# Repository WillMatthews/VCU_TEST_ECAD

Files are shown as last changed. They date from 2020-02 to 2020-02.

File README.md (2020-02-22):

# VCU TEST ECAD
VCU to Beaglebone breakout hardware for testing the VCU, and future continuous integration work.

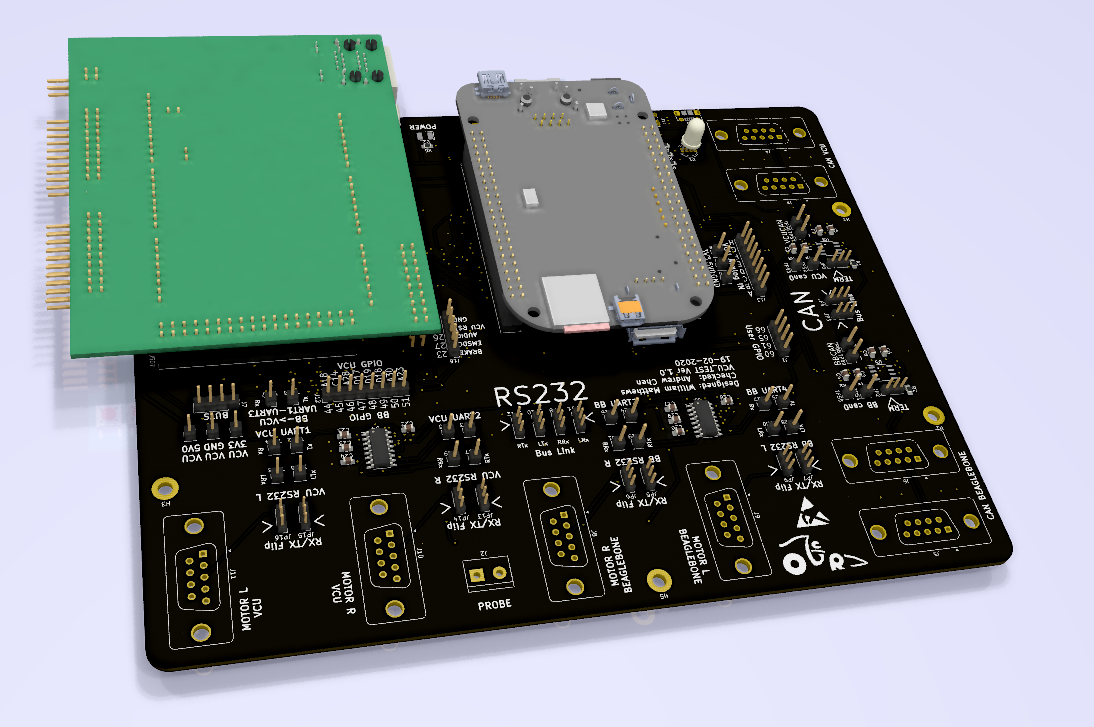
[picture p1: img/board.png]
Board Image


## Schematic and PCB

The project is made in KiCad. Which can be obtained for free! [KiCad 5.0](http://kicad-pcb.org/download/)
All project files are in the `Kicad/` subdirectory.

## Components

The design is made for power supply of 5V from either a MicroUSB or USBC power supply.
The target current consumption by this device is 1A under load, but may be higher.

We use a SAM e70 Xplained evaluation kit as the VCU.

A Beaglebone black as the test host.

### CAN
We use TCAN1042 CAN transcievers.

Both on can0 of VCU and Beaglebone.

### RS232 (Motor Emulation)
We use MAX 3232 chips for:

LEFT: Beaglebone UART2, VCU UART 1

RIGHT: Beaglebone UART4, VCU UART 2

## Signals
See pinreference_bb_vcu.ods for which beaglebone GPIOs go where (needs updating)!

## Continuous Integration
We plan to use Jenkins CI, but this is yet to be figured out and made a reality.

## Future Work

We also have plans for a DAC daughterboard to supply analogue signals to the sensors on VCU, reference also on above document.

THINGS TO DO:
- [ ] Does TLV5631 actually have SPI or is the datasheet blatantly lying to my face?
  - Now made a "daugherboard" project if required.
- [x] Put correct CAN chips
- [ ] Confirm design with team
- [x] Layout
- [x] GET LAYOUT FOR THE VCU PINS !!! Cannot find anywhere !!!
- [ ] Start test software repo
- [ ] Better documentation for pins

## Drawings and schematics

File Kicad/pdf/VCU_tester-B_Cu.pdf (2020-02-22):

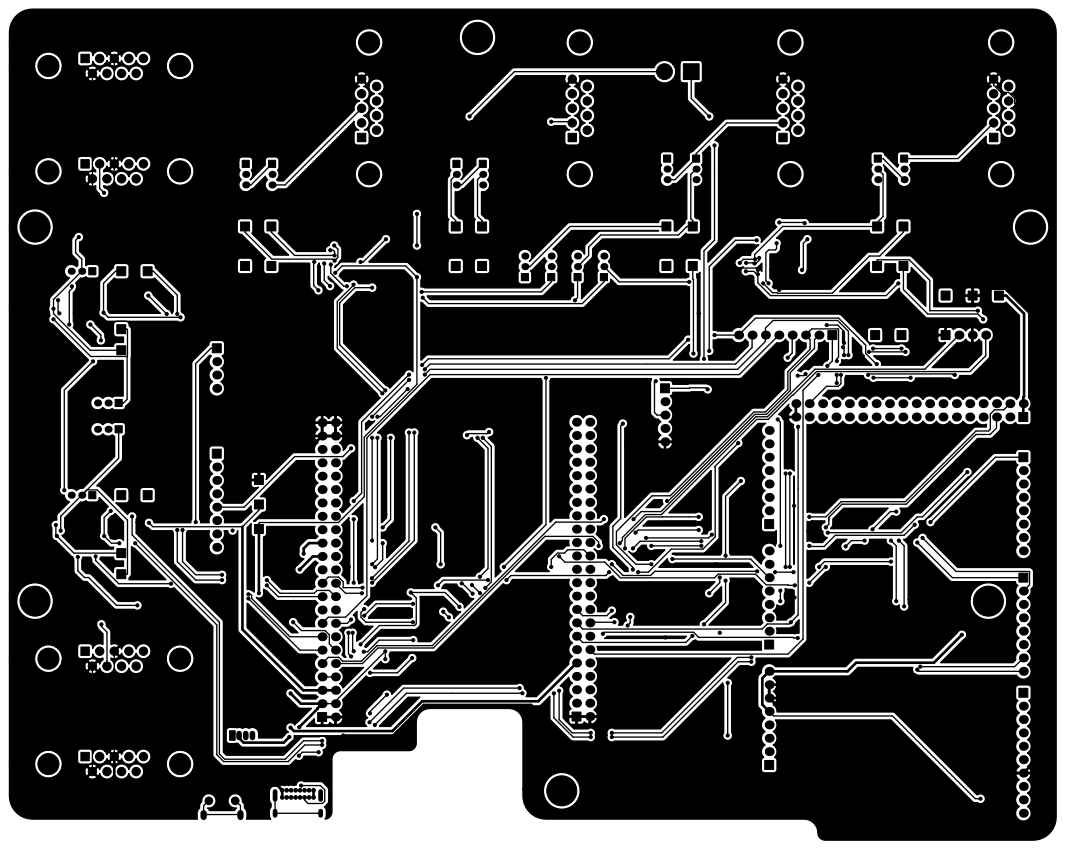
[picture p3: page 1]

File: VCU_tester.kicad_pcb Sheet:
Id: 1/1 Title: VCU Test Board

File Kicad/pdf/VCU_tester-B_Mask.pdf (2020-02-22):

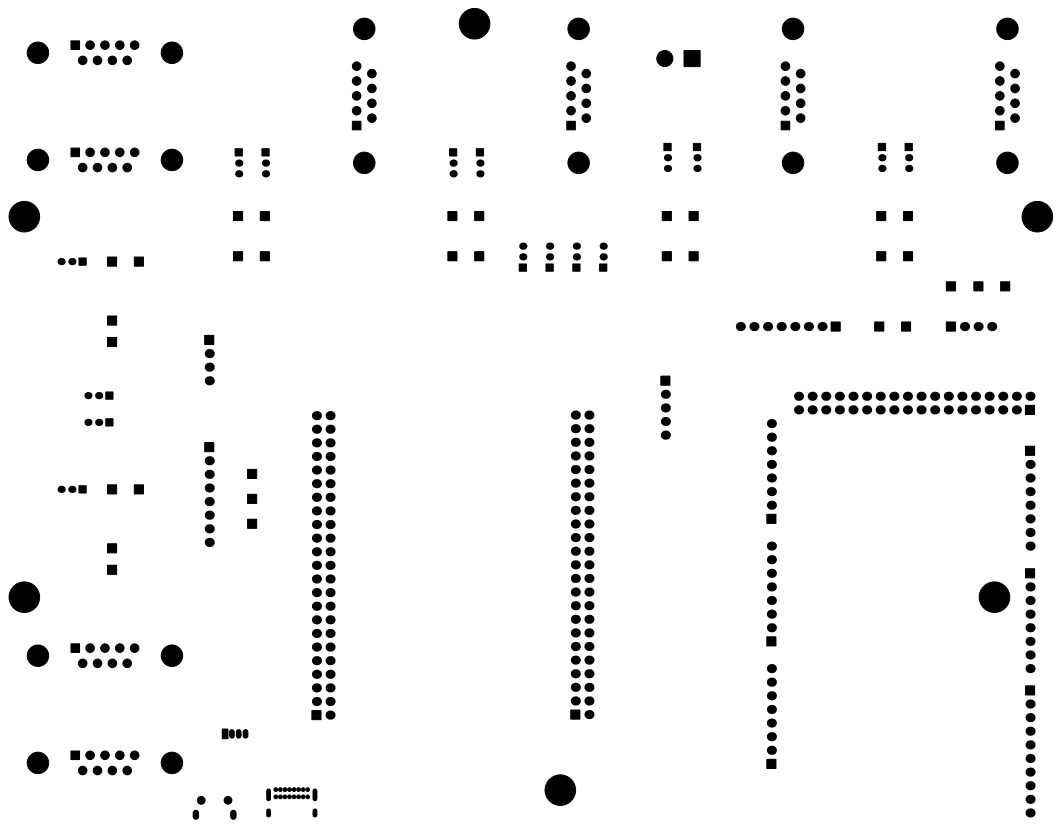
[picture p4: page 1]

File: VCU_tester.kicad_pcb Sheet:
Id: 1/1 Title: VCU Test Board

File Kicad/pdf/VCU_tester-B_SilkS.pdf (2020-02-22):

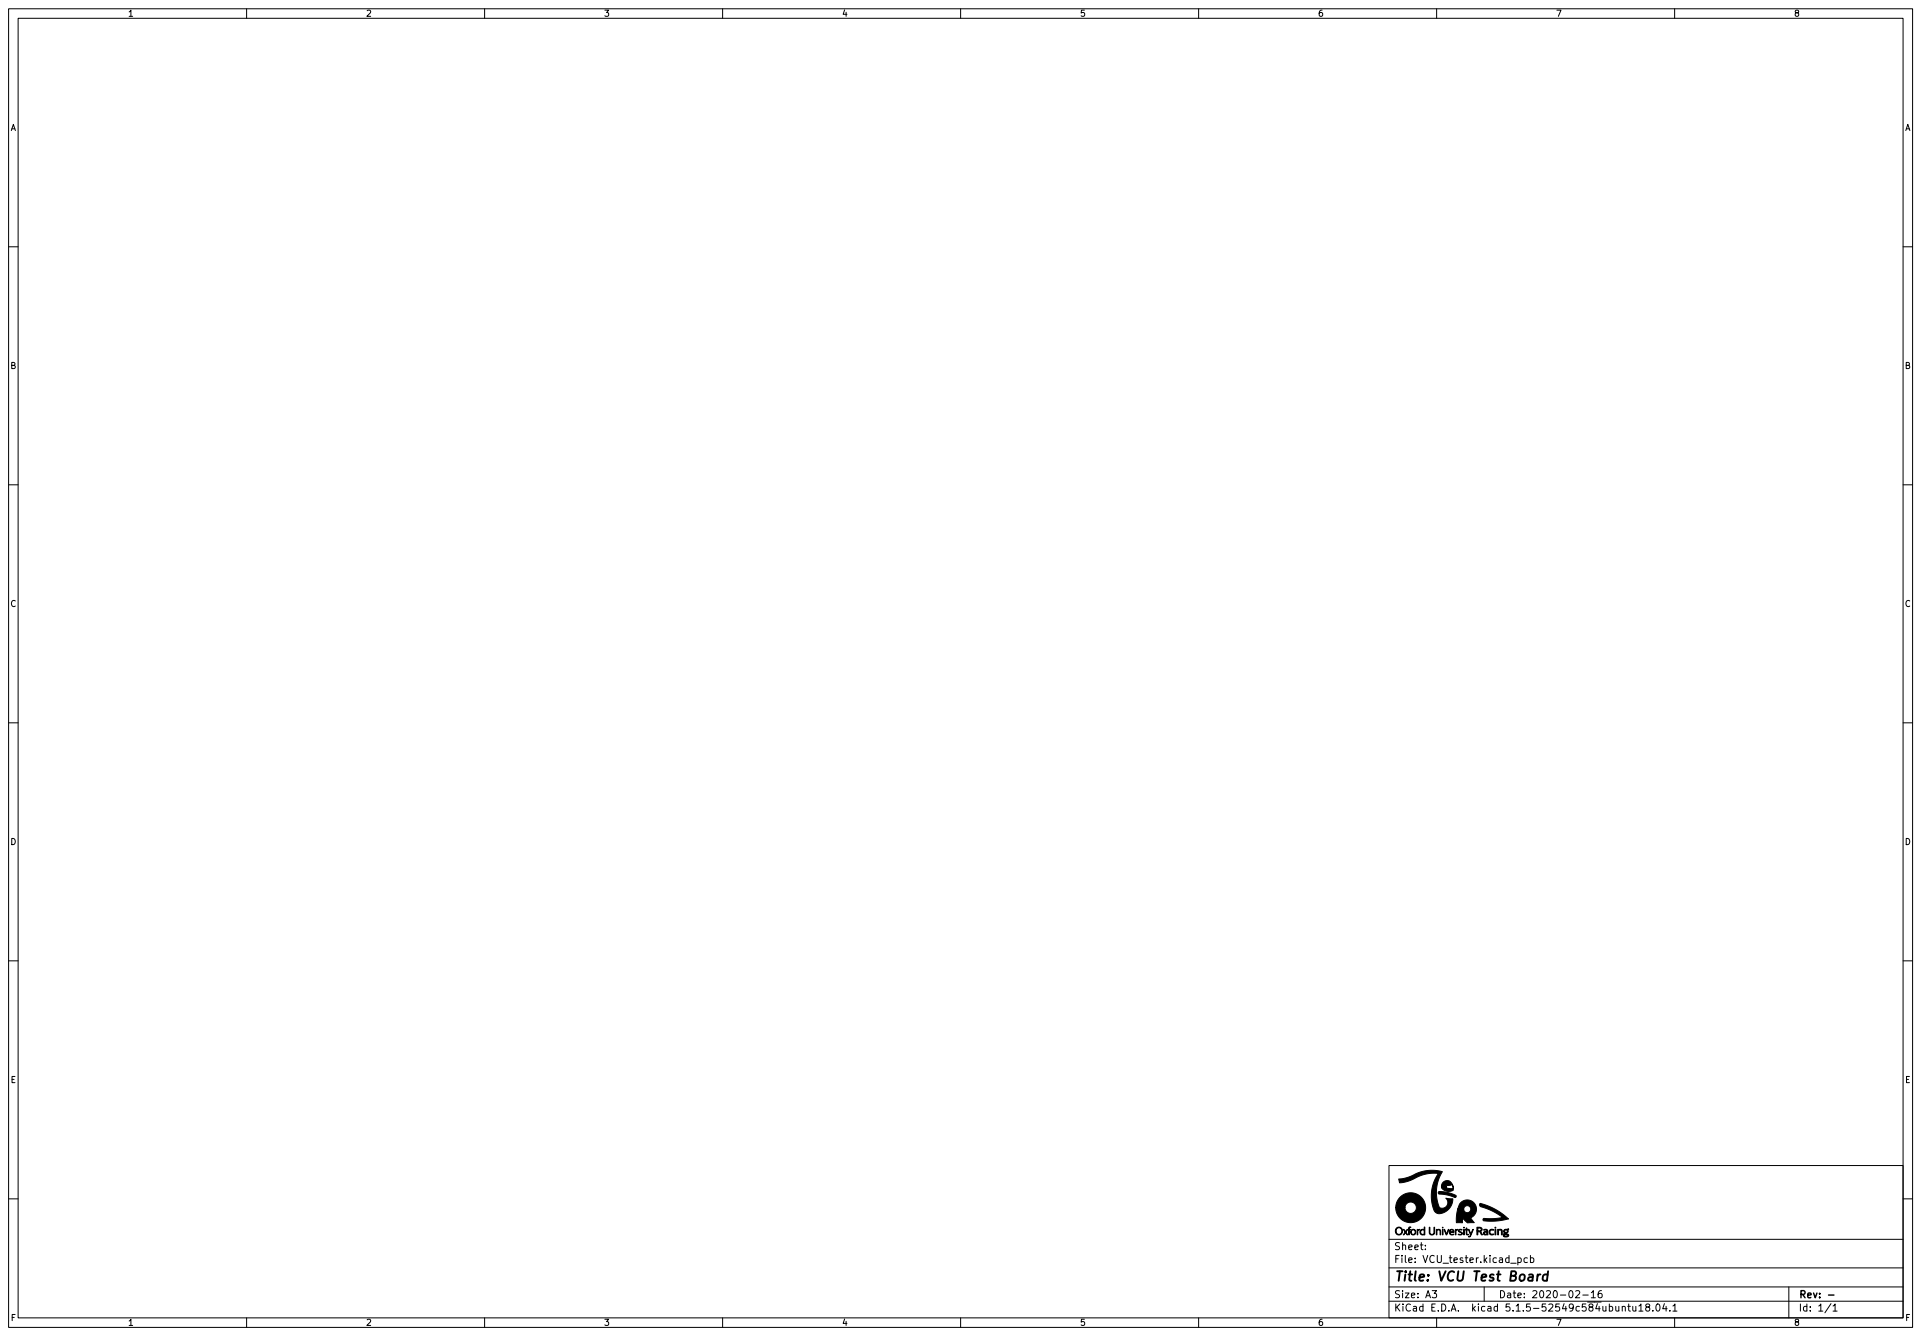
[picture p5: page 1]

File: VCU_tester.kicad_pcb Sheet:
Id: 1/1 Title: VCU Test Board

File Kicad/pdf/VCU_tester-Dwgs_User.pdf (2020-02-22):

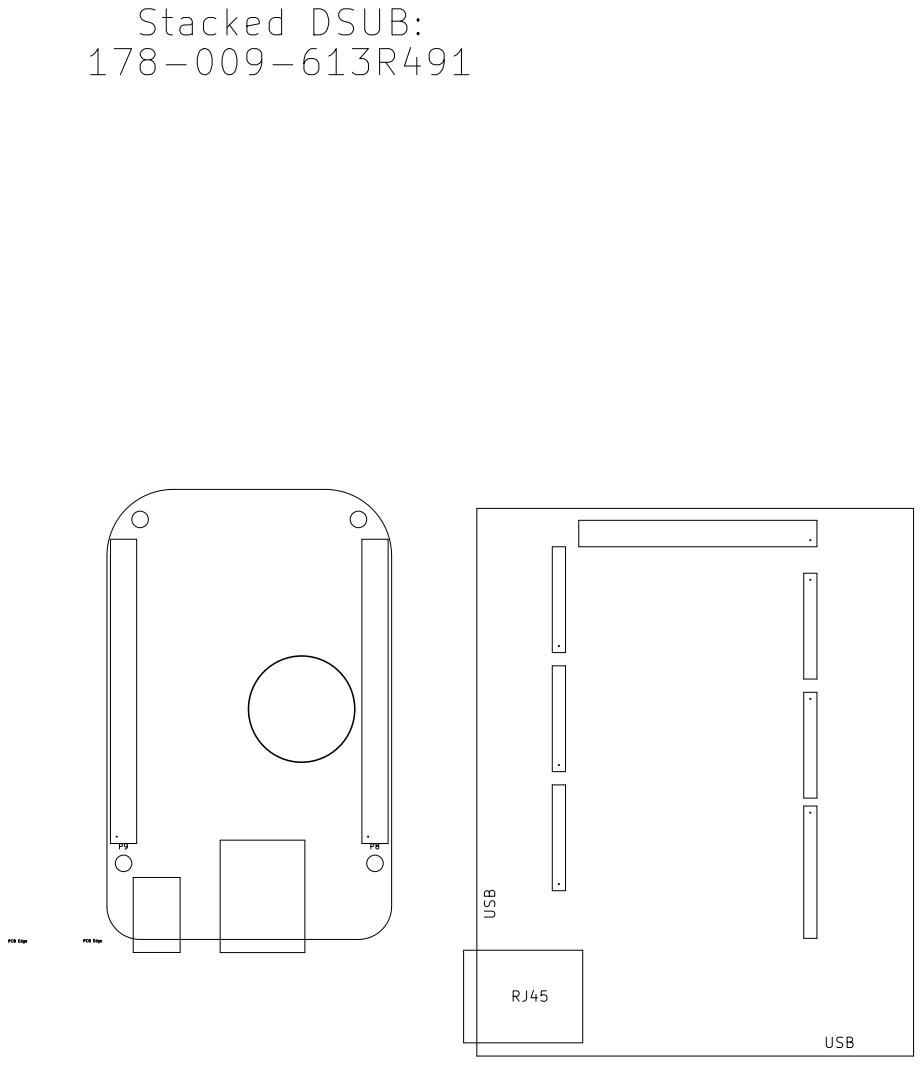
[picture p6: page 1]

File: VCU_tester.kicad_pcb Sheet: Stacked DSUB:

Id: 1/1 Title: VCU Test Board

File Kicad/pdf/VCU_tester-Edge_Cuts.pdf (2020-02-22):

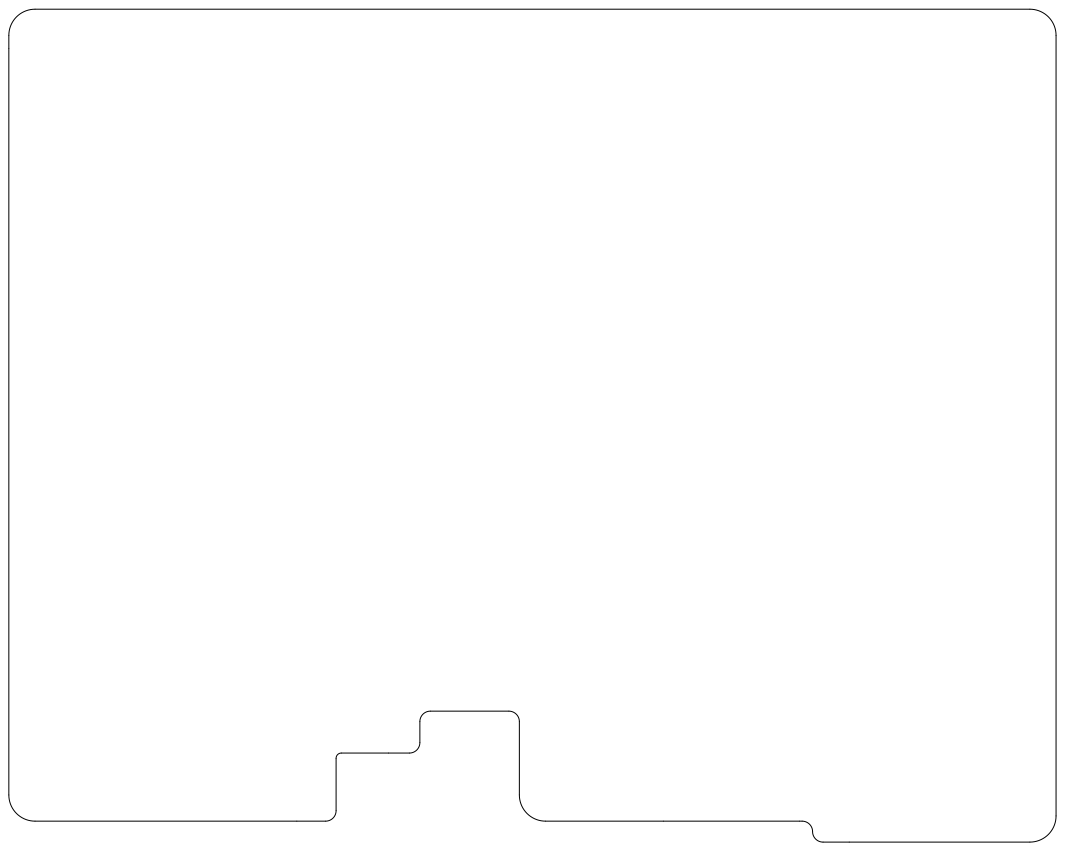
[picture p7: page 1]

File: VCU_tester.kicad_pcb Sheet:
Id: 1/1 Title: VCU Test Board

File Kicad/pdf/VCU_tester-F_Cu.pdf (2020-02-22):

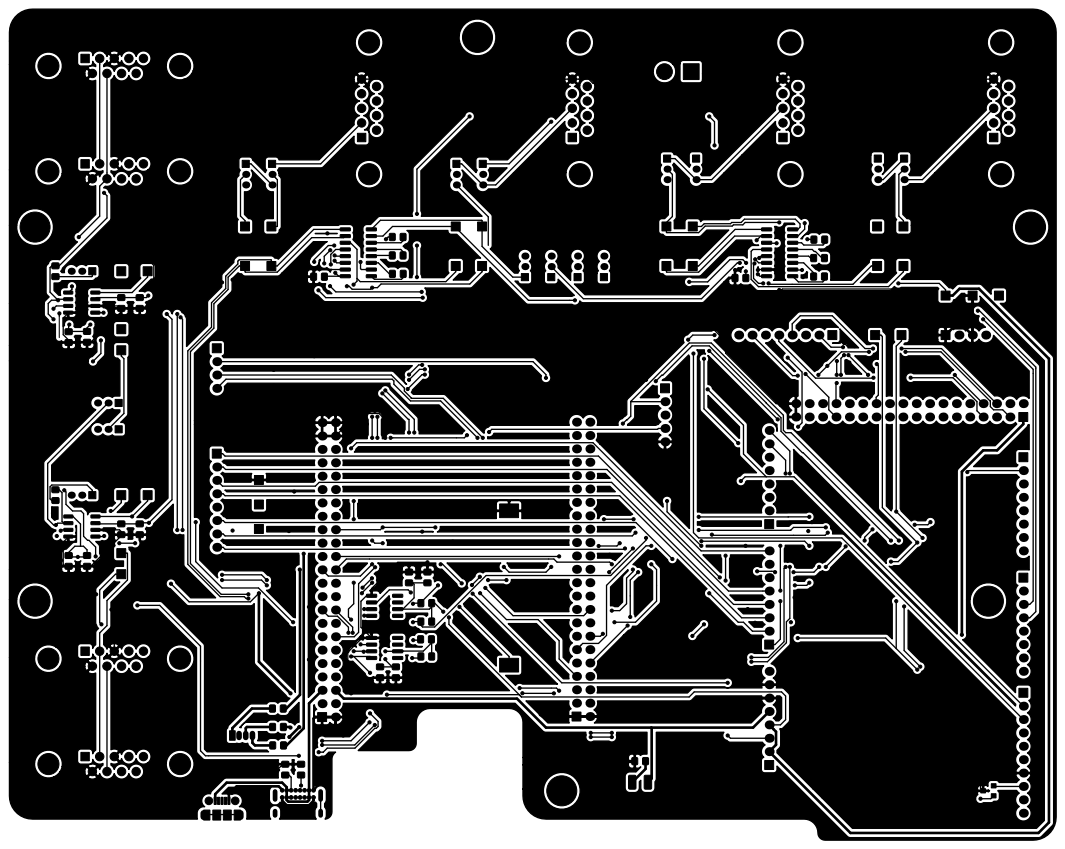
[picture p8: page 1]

File: VCU_tester.kicad_pcb Sheet:
Id: 1/1 Title: VCU Test Board

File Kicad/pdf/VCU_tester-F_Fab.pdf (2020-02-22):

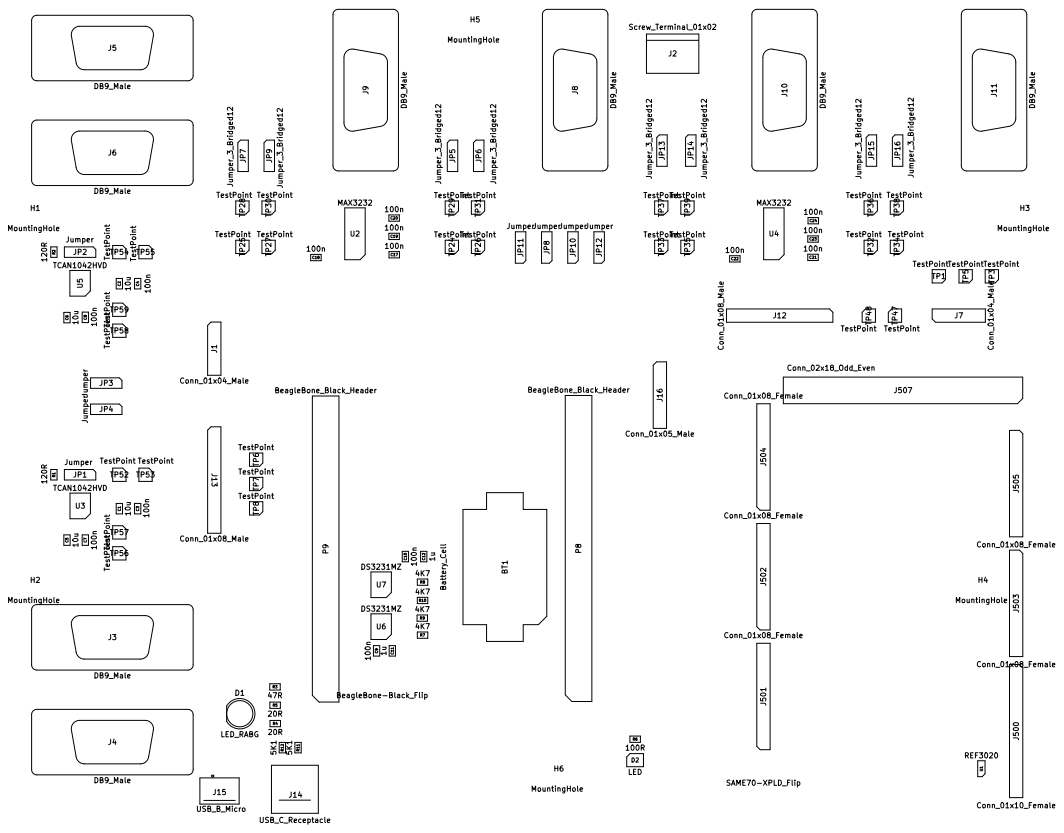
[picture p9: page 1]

File: VCU_tester.kicad_pcb Sheet:
Id: 1/1 Title: VCU Test Board

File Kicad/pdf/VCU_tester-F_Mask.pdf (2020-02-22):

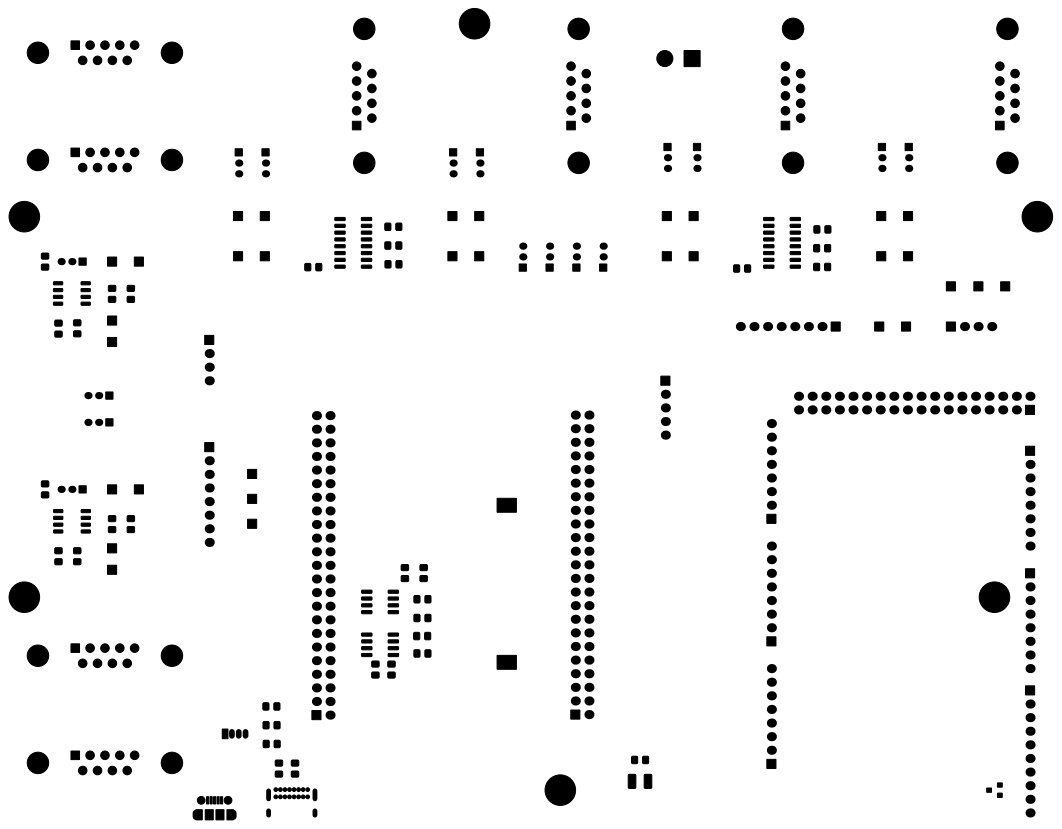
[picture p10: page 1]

File: VCU_tester.kicad_pcb Sheet:
Id: 1/1 Title: VCU Test Board

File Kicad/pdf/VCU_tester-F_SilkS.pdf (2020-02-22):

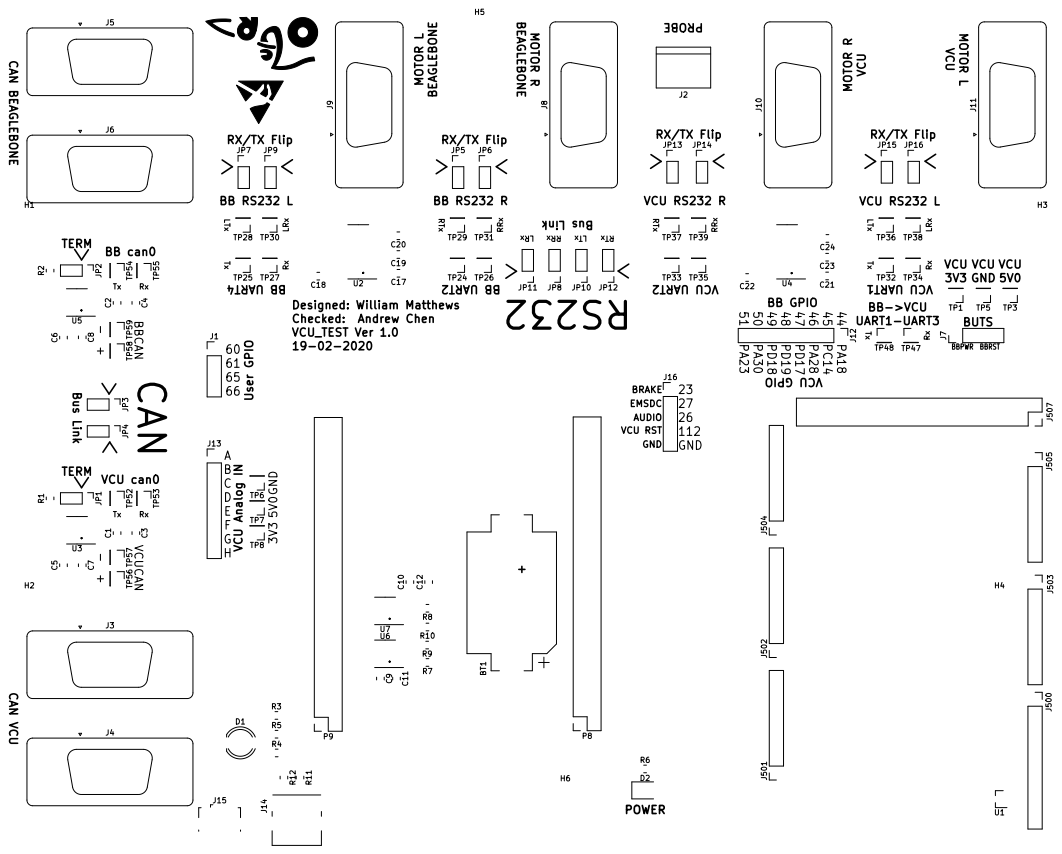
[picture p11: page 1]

File: VCU_tester.kicad_pcb Sheet:
Id: 1/1 Title: VCU Test Board

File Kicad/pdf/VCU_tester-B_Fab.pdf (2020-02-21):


File: VCU_tester.kicad_pcb Sheet:
Id: 1/1 Title: VCU Test Board

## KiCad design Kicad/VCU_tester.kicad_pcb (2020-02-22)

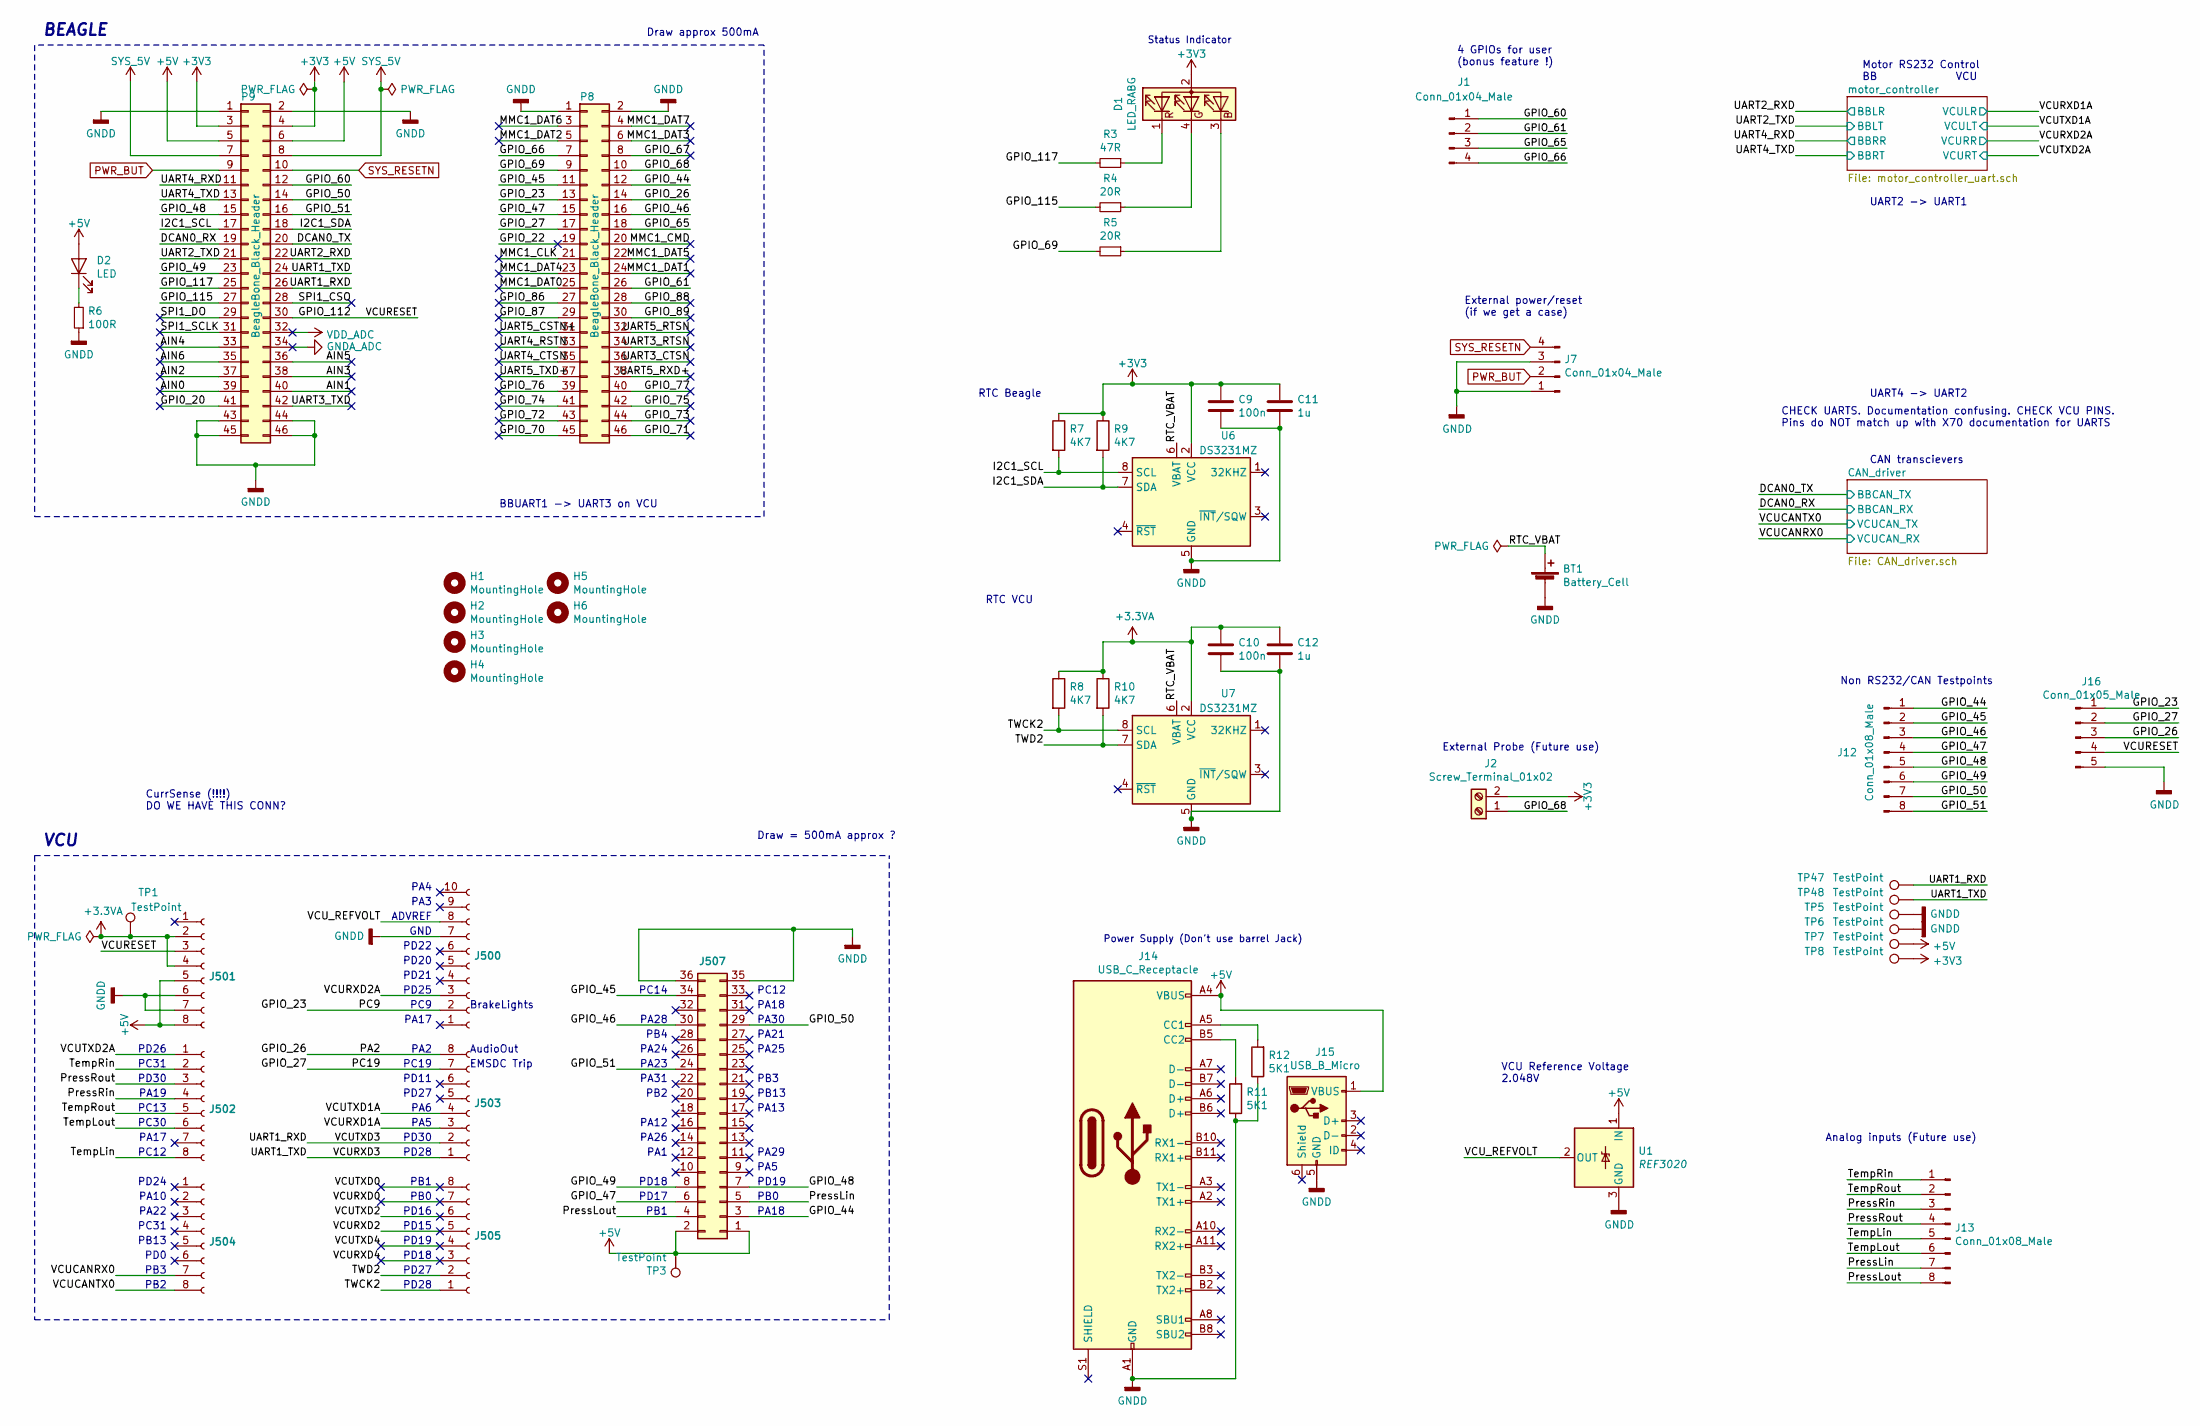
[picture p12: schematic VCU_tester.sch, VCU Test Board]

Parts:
BT1: Battery_Cell; BatteryHolder_Keystone_1060_1x2032; Part BU2032SM-FH-GCT-ND
C9, C10: 100n; C_0805_2012Metric_Pad1.15x1.40mm_HandSolder
C11, C12: 1u; C_0805_2012Metric_Pad1.15x1.40mm_HandSolder
D1: LED_RABG; LED_D5.0mm-4_RGB; Part WP154A4SEJ3VBDZGW/CA
D2: LED; D_1210_3225Metric_Pad1.42x2.65mm_HandSolder; Part 516-2672-1-ND
H1, H2, H3, H4, H5, H6: MountingHole; MountingHole_3.2mm_M3_ISO7380_Pad
J1, J7: Conn_01x04_Male; PinHeader_1x04_P2.54mm_Vertical
J2: Screw_Terminal_01x02; TerminalBlock_bornier-2_P5.08mm; Part 282837-2
J12, J13: Conn_01x08_Male; PinHeader_1x08_P2.54mm_Vertical
J14: USB_C_Receptacle; USB_C_Receptacle_GCT_USB4085; Part 2073-USB4085-GF-ACT-ND
J15: USB_B_Micro; USB_Micro-B_Molex-105017-0001
J16: Conn_01x05_Male; PinHeader_1x05_P2.54mm_Vertical
J500: Conn_01x10_Female; PinSocket_1x10_P2.54mm_Vertical
J501, J502, J503, J504, J505: Conn_01x08_Female; PinSocket_1x08_P2.54mm_Vertical
J507: Conn_02x18_Odd_Even; PinSocket_2x18_P2.54mm_Vertical
P8, P9: BeagleBone_Black_Header; PinHeader_2x23_P2.54mm_Vertical_Flip
R3: 47R; R_0805_2012Metric_Pad1.15x1.40mm_HandSolder
R4, R5: 20R; R_0805_2012Metric_Pad1.15x1.40mm_HandSolder
R6: 100R; R_0805_2012Metric_Pad1.15x1.40mm_HandSolder
R7, R8, R9, R10: 4K7; R_0805_2012Metric_Pad1.15x1.40mm_HandSolder
R11, R12: 5K1; R_0805_2012Metric_Pad1.15x1.40mm_HandSolder
TP1, TP3, TP5, TP6, TP7, TP8, TP47, TP48: TestPoint; PinHeader_1x01_P2.54mm_Vertical
U1: REF3020; SOT-23; Part 296-26321-1-ND
U6, U7: DS3231MZ; SOIC-8_3.9x4.9mm_P1.27mm

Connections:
+3.3VA: C10.1, C12.1, J501.2, J501.4, R8.1, R10.1, TP1.1, U7.2 (VCC); also elsewhere on the board
+3V3: C9.1, C11.1, D1.2 (A), J2.2, P9.3, P9.4, R7.1, R9.1, TP8.1, U6.2 (VCC); also elsewhere on the board
+5V: D2.2 (A), J14.A4 (VBUS), J14.A9 (VBUS), J14.B4 (VBUS), J14.B9 (VBUS), J15.1 (VBUS), J501.5, J501.8, J507.1, J507.2, P9.5, P9.6, TP3.1, TP7.1, U1.1 (IN); also elsewhere on the board
/AIN0: P9.39
/AIN1: P9.40
/AIN2: P9.37
/AIN3: P9.38
/AIN4: P9.33
/AIN5: P9.36
/AIN6: P9.35
/DCAN0_RX: P9.19; also elsewhere on the board
/DCAN0_TX: P9.20; also elsewhere on the board
/GPI0_20: P9.41
/GPIO_22: P8.19
/GPIO_23: J16.1, J500.2, P8.13
/GPIO_26: J16.3, J503.8, P8.14
/GPIO_27: J16.2, J503.7, P8.17
/GPIO_44: J12.1, J507.3, P8.12
/GPIO_45: J12.2, J507.34, P8.11
/GPIO_46: J12.3, J507.30, P8.16
/GPIO_47: J12.4, J507.6, P8.15
/GPIO_48: J12.5, J507.7, P9.15
/GPIO_49: J12.6, J507.8, P9.23
/GPIO_50: J12.7, J507.29, P9.14
/GPIO_51: J12.8, J507.24, P9.16
/GPIO_60: J1.1, P9.12
/GPIO_61: J1.2, P8.26
/GPIO_65: J1.3, P8.18
/GPIO_66: J1.4, P8.7
/GPIO_67: P8.8
/GPIO_68: J2.1, P8.10
/GPIO_69: P8.9, R5.2
/GPIO_70: P8.45
/GPIO_71: P8.46
/GPIO_72: P8.43
/GPIO_73: P8.44
/GPIO_74: P8.41
/GPIO_75: P8.42
/GPIO_76: P8.39
/GPIO_77: P8.40
/GPIO_86: P8.27
/GPIO_87: P8.29
/GPIO_88: P8.28
/GPIO_89: P8.30
/GPIO_112: J16.4, J501.3, P9.30
/GPIO_115: P9.27, R4.2
/GPIO_117: P9.25, R3.2
/I2C1_SCL: P9.17, R7.2, U6.8 (SCL)
/I2C1_SDA: P9.18, R9.2, U6.7 (SDA)
/MMC1_CLK: P8.21
/MMC1_CMD: P8.20
/MMC1_DAT0: P8.25
/MMC1_DAT1: P8.24
/MMC1_DAT2: P8.5
/MMC1_DAT3: P8.6
/MMC1_DAT4: P8.23
/MMC1_DAT5: P8.22
/MMC1_DAT6: P8.3
/MMC1_DAT7: P8.4
/PressLin: J13.7, J507.5
/PressLout: J13.8, J507.4
/PressRin: J13.3, J502.4
/PressRout: J13.4, J502.3
/RTC_VBAT: BT1.1 (+), U6.6 (VBAT), U7.6 (VBAT)
/SPI1_CSO: P9.28
/SPI1_DO: P9.29
/SPI1_SCLK: P9.31
/TWCK2: J505.1, R8.2, U7.8 (SCL)
/TWD2: J505.2, R10.2, U7.7 (SDA)
/TempLin: J13.5, J502.8
/TempLout: J13.6, J502.6
/TempRin: J13.1, J502.2
/TempRout: J13.2, J502.5
/UART1_RXD: J503.2, P9.26, TP47.1
/UART1_TXD: J503.1, P9.24, TP48.1
/UART2_RXD: P9.22; also elsewhere on the board
/UART2_TXD: P9.21; also elsewhere on the board
/UART3_CTSN: P8.36
/UART3_RTSN: P8.34
/UART3_TXD: P9.42
/UART4_CTSN: P8.35
/UART4_RSTN: P8.33
/UART4_RXD: P9.11; also elsewhere on the board
/UART4_TXD: P9.13; also elsewhere on the board
/UART5_CSTN+: P8.31
/UART5_RTSN: P8.32
/UART5_RXD+: P8.38
/UART5_TXD+: P8.37
/VCUCANRX0: J504.7; also elsewhere on the board
/VCUCANTX0: J504.8; also elsewhere on the board
/VCURXD0: J505.7
/VCURXD1A: J503.3; also elsewhere on the board
/VCURXD2: J505.5
/VCURXD2A: J500.3; also elsewhere on the board
/VCURXD4: J505.3
/VCUTXD0: J505.8
/VCUTXD1A: J503.4; also elsewhere on the board
/VCUTXD2: J505.6
/VCUTXD2A: J502.1; also elsewhere on the board
/VCUTXD4: J505.4
/VCU_REFVOLT: J500.8, U1.2 (OUT)
GNDA_ADC: P9.34
GNDD: BT1.2 (-), C9.2, C10.2, C11.2, C12.2, J7.1, J7.3, J14.A1 (GND), J14.A12 (GND), J14.B1 (GND), J14.B12 (GND), J15.5 (GND), J16.5, J500.7, J501.6, J501.7, J507.35, J507.36, P8.1, P8.2, P9.1, P9.2, P9.43, P9.44, P9.45, P9.46, R6.1, R11.1, R12.1, TP5.1, TP6.1, U1.3 (GND), U6.5 (GND), U7.5 (GND); also elsewhere on the board
unnamed: D1.1 (RK), R3.1
unnamed: D1.3 (BK), R5.1
unnamed: D1.4 (GK), R4.1
unnamed: D2.1 (K), R6.2
unnamed: J14.A5 (CC1), R12.2
unnamed: J14.B5 (CC2), R11.2
PWR_BUT: J7.2, P9.9
SYS_5V: P9.7, P9.8
SYS_RESETN: J7.4, P9.10
VDD_ADC: P9.32

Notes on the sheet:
4 GPIOs for user (bonus feature !)
UART2 -> UART1
UART4 -> UART2
Motor RS232 Control BB VCU
BBUART1 -> UART3 on VCU
CAN transcievers
BEAGLE
VCU
Status Indicator
CHECK UARTS. Documentation confusing. CHECK VCU PINS. Pins do NOT match up with X70 documentation for UARTS
CurrSense (!!!!) DO WE HAVE THIS CONN?
Non RS232/CAN Testpoints
External power/reset (if we get a case)
Draw = 500mA approx ?
Draw approx 500mA
Power Supply (Don't use barrel Jack)
RTC Beagle
RTC VCU
VCU Reference Voltage 2.048V
External Probe (Future use)
Analog inputs (Future use)
AudioOut
EMSDC Trip
PA4
PA3
ADVREF
GND
PD22
PD20
PD21
PD25
PC9
PA17
PA2
PC19
PD11
PD27
PA6
PA5
PD30

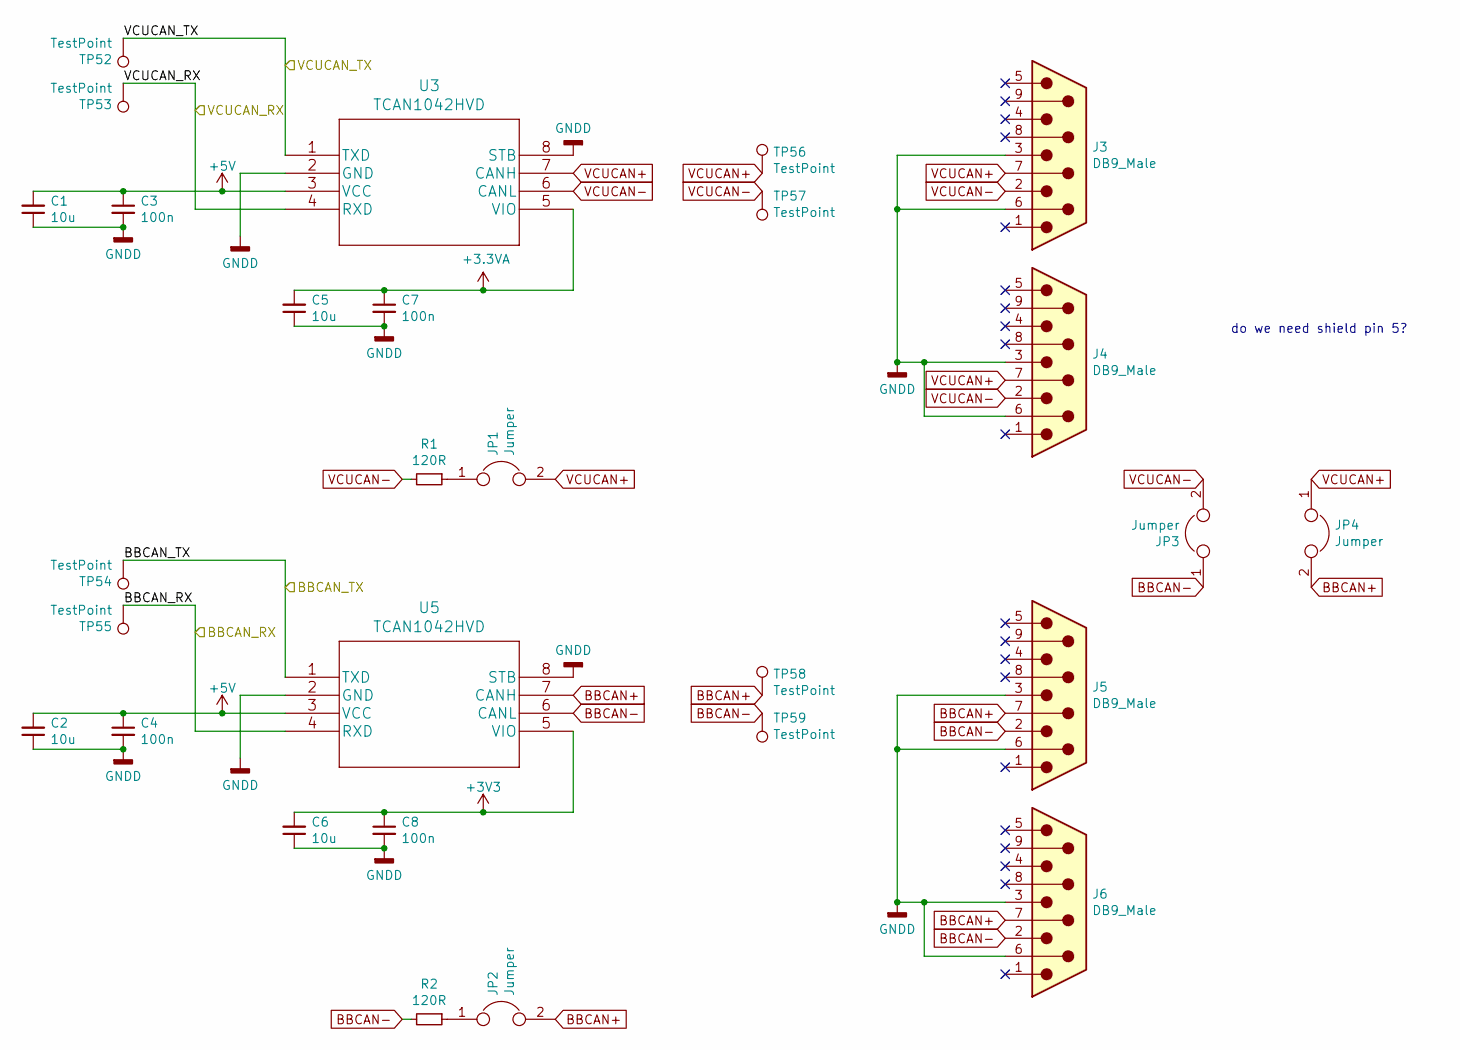
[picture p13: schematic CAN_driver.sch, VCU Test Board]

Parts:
C1, C2, C5, C6: 10u; C_0805_2012Metric_Pad1.15x1.40mm_HandSolder
C3, C4, C7, C8: 100n; C_0805_2012Metric_Pad1.15x1.40mm_HandSolder
J3, J4, J5, J6: DB9_Male; DSUB-9_Male_Vertical_P2.77x2.84mm_MountingHoles; Part 5747840-3
JP1, JP2, JP3, JP4: Jumper; PinHeader_1x03_P2.00mm_Vertical; Part SPN02SXCN-RC
R1, R2: 120R; R_0805_2012Metric_Pad1.15x1.40mm_HandSolder
TP52, TP53, TP54, TP55, TP56, TP57, TP58, TP59: TestPoint; PinHeader_1x01_P2.54mm_Vertical
U3, U5: TCAN1042HVD; SO-8_3.9x4.9mm_P1.27mm; Part 296-48672-1-ND

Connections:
+3.3VA: C5.2, C7.1, U3.5 (VIO); also elsewhere on the board
+3V3: C6.2, C8.1, U5.5 (VIO); also elsewhere on the board
+5V: C1.2, C2.2, C3.1, C4.1, U3.3 (VCC), U5.3 (VCC); also elsewhere on the board
/DCAN0_RX: TP55.1, U5.4 (RXD); also elsewhere on the board
/DCAN0_TX: TP54.1, U5.1 (TXD); also elsewhere on the board
/VCUCANRX0: TP53.1, U3.4 (RXD); also elsewhere on the board
/VCUCANTX0: TP52.1, U3.1 (TXD); also elsewhere on the board
BBCAN+: J5.7, J6.7, JP2.2, JP4.2, TP58.1, U5.7 (CANH)
BBCAN-: J5.2, J6.2, JP3.1, R2.2, TP59.1, U5.6 (CANL)
GNDD: C1.1, C2.1, C3.2, C4.2, C5.1, C6.1, C7.2, C8.2, J3.3, J3.6, J4.3, J4.6, J5.3, J5.6, J6.3, J6.6, U3.2 (GND), U3.8 (STB), U5.2 (GND), U5.8 (STB); also elsewhere on the board
unnamed: JP1.1, R1.1
unnamed: JP2.1, R2.1
VCUCAN+: J3.7, J4.7, JP1.2, JP4.1, TP56.1, U3.7 (CANH)
VCUCAN-: J3.2, J4.2, JP3.2, R1.2, TP57.1, U3.6 (CANL)

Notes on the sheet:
do we need shield pin 5?

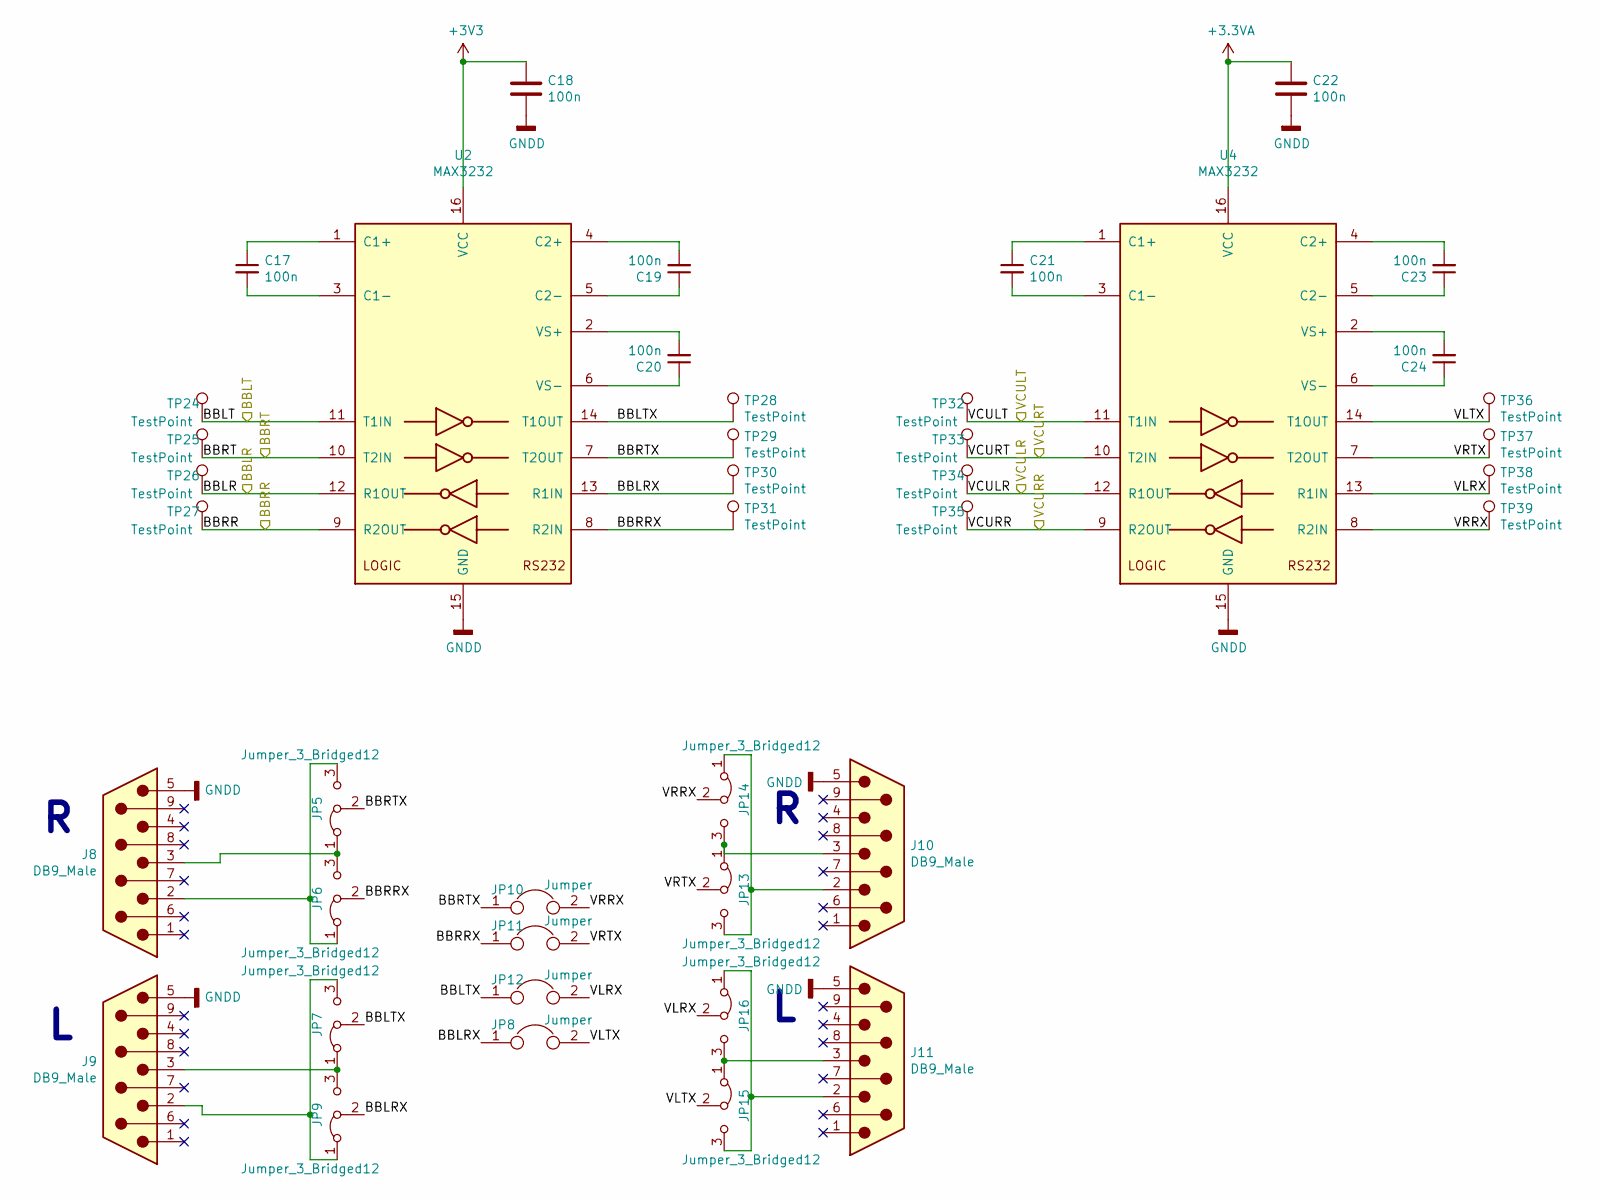
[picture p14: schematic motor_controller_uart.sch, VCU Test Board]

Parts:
C17, C18, C19, C20, C21, C22, C23, C24: 100n; C_0805_2012Metric_Pad1.15x1.40mm_HandSolder
J8, J9, J10, J11: DB9_Male; DSUB-9_Male_Vertical_P2.77x2.84mm_MountingHoles; Part 5747840-3
JP5, JP6, JP7, JP9, JP13, JP14, JP15, JP16: Jumper_3_Bridged12; PinHeader_1x03_P2.00mm_Vertical; Part SPN02SXCN-RC
JP8, JP10, JP11, JP12: Jumper; PinHeader_1x03_P2.00mm_Vertical; Part SPN02SXCN-RC
TP24, TP25, TP26, TP27, TP28, TP29, TP30, TP31, TP32, TP33, TP34, TP35, TP36, TP37, TP38, TP39: TestPoint; PinHeader_1x01_P2.54mm_Vertical
U2, U4: MAX3232; SOIC-16_3.9x9.9mm_P1.27mm; Part MAX3232CSE+TCT-ND

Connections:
+3.3VA: C22.1, U4.16 (VCC); also elsewhere on the board
+3V3: C18.1, U2.16 (VCC); also elsewhere on the board
/UART2_RXD: TP26.1, U2.12 (R1OUT); also elsewhere on the board
/UART2_TXD: TP24.1, U2.11 (T1IN); also elsewhere on the board
/UART4_RXD: TP27.1, U2.9 (R2OUT); also elsewhere on the board
/UART4_TXD: TP25.1, U2.10 (T2IN); also elsewhere on the board
/VCURXD1A: TP34.1, U4.12 (R1OUT); also elsewhere on the board
/VCURXD2A: TP35.1, U4.9 (R2OUT); also elsewhere on the board
/VCUTXD1A: TP32.1, U4.11 (T1IN); also elsewhere on the board
/VCUTXD2A: TP33.1, U4.10 (T2IN); also elsewhere on the board
/motor_controller/BBLRX: JP8.1, JP9.2 (C), TP30.1, U2.13 (R1IN)
/motor_controller/BBLTX: JP7.2 (C), JP12.1, TP28.1, U2.14 (T1OUT)
/motor_controller/BBRRX: JP6.2 (C), JP11.1, TP31.1, U2.8 (R2IN)
/motor_controller/BBRTX: JP5.2 (C), JP10.1, TP29.1, U2.7 (T2OUT)
/motor_controller/VLRX: JP12.2, JP16.2 (C), TP38.1, U4.13 (R1IN)
/motor_controller/VLTX: JP8.2, JP15.2 (C), TP36.1, U4.14 (T1OUT)
/motor_controller/VRRX: JP10.2, JP14.2 (C), TP39.1, U4.8 (R2IN)
/motor_controller/VRTX: JP11.2, JP13.2 (C), TP37.1, U4.7 (T2OUT)
GNDD: C18.2, C22.2, J8.5, J9.5, J10.5, J11.5, U2.15 (GND), U4.15 (GND); also elsewhere on the board
unnamed: C17.1, U2.1 (C1+)
unnamed: C17.2, U2.3 (C1-)
unnamed: C19.1, U2.5 (C2-)
unnamed: C19.2, U2.4 (C2+)
unnamed: C20.1, U2.6 (VS-)
unnamed: C20.2, U2.2 (VS+)
unnamed: C21.1, U4.1 (C1+)
unnamed: C21.2, U4.3 (C1-)
unnamed: C23.1, U4.5 (C2-)
unnamed: C23.2, U4.4 (C2+)
unnamed: C24.1, U4.6 (VS-)
unnamed: C24.2, U4.2 (VS+)
unnamed: J8.2, JP5.3 (B), JP6.1 (A)
unnamed: J8.3, JP5.1 (A), JP6.3 (B)
unnamed: J9.2, JP7.3 (B), JP9.1 (A)
unnamed: J9.3, JP7.1 (A), JP9.3 (B)
unnamed: J10.2, JP13.3 (B), JP14.1 (A)
unnamed: J10.3, JP13.1 (A), JP14.3 (B)
unnamed: J11.2, JP15.3 (B), JP16.1 (A)
unnamed: J11.3, JP15.1 (A), JP16.3 (B)

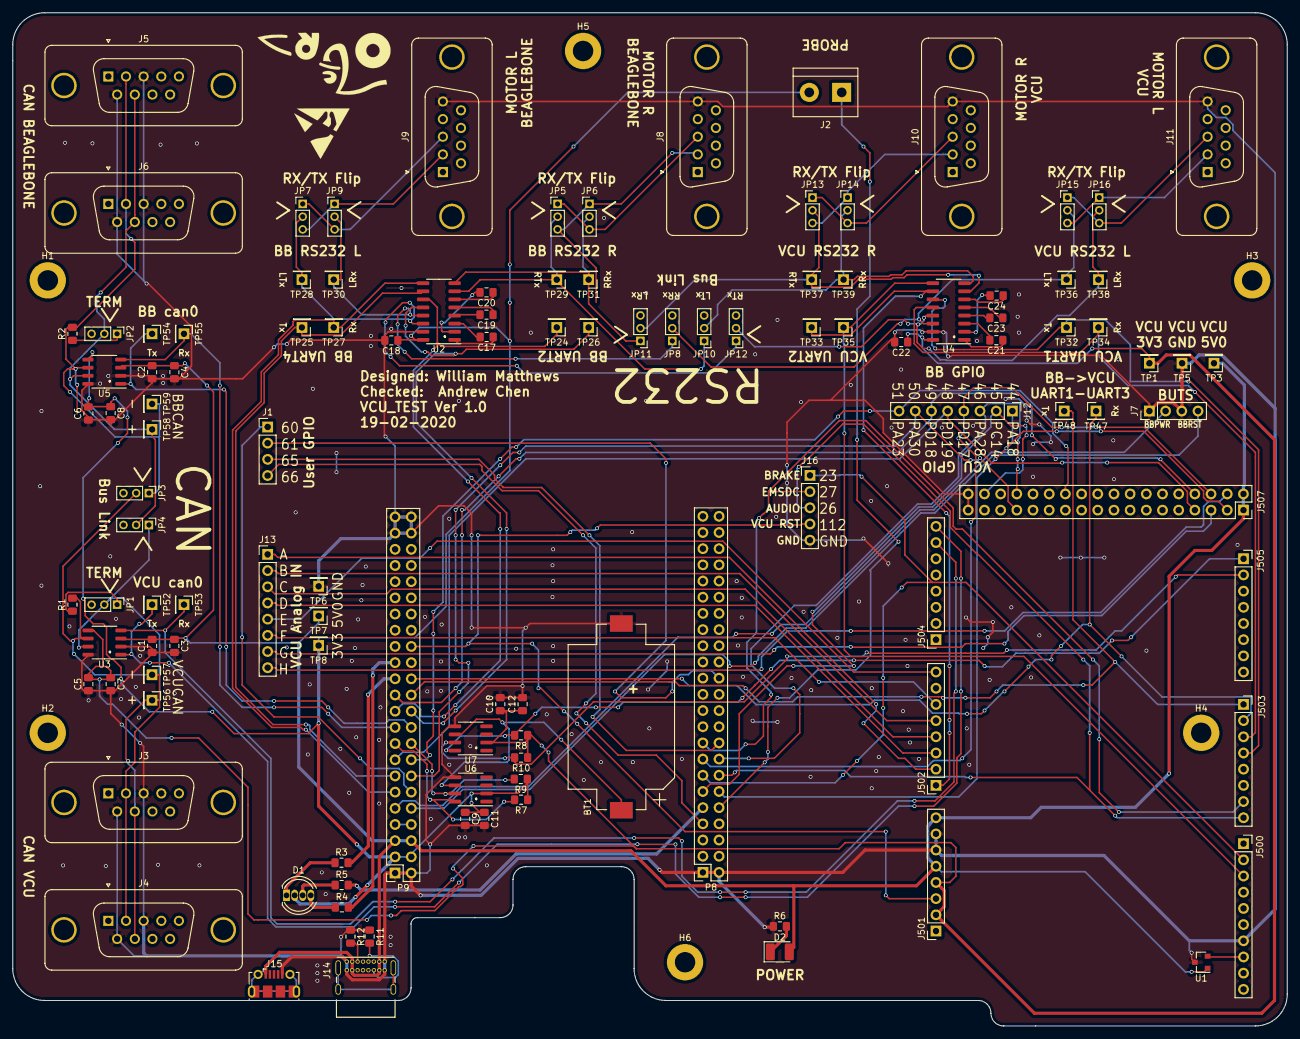
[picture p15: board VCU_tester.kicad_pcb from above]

Board: 2 copper layers, 200.0 x 159.0 mm, 121 parts (0 on the bottom side), 95 nets.

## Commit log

2020-02-12 initial commit, BB black template
    [VCU_tester.kicad_pcb, VCU_tester.sch]
2020-02-12 CAN parts added, rs232 parts added, gpio added
    [CAN_driver.sch, VCU_tester.kicad_pcb, VCU_tester.sch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]
2020-02-13 added vcu pinout, still lots needs doing
    [CAN_driver.sch, VCU_tester.sch, motor_controller_uart.sch]
2020-02-13 added more vcu pinout, just need to route UART, figure out GPIO problem
    [CAN_driver.sch, VCU_tester.sch]
2020-02-13 vcu pinout done
    [VCU_tester.sch]
2020-02-14 added pin names vcu, rs232 mcguffins, losing hope
    [CAN_driver.sch, VCU_tester.sch, motor_controller_uart.sch]
2020-02-14 misread diagram.. fixed
    [VCU_tester.sch]
2020-02-15 sleep isn't real. Fixed pins. DAC hell. Nearly done on schematic.
    [CAN_driver.sch, VCU_tester.sch, pinreference_bb_vcu.ods]
2020-02-15 no connects and documentation
    [VCU_tester.sch, pinreference_bb_vcu.ods]
2020-02-16 changed CAN chips
    [CAN_driver.sch]
2020-02-16 removed dac, added jumpers, ready for parting up
    [CAN_driver.sch, VCU_tester.sch, motor_controller_uart.sch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]
2020-02-16 parts assigned, layout started, CAN and RS232 sides done
    [CAN_driver.sch, VCU_tester.kicad_pcb, VCU_tester.sch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]
2020-02-16 added worksheet, shuffled board around to make it smaller
    [CAN_driver.sch, VCU_tester.kicad_pcb, VCU_tester.sch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]
2020-02-16 pins corrected, RTC added
    [VCU_tester.kicad_pcb, VCU_tester.sch]
2020-02-17 routing start
    [VCU_tester.kicad_pcb, VCU_tester.sch]
2020-02-17 cant remember what I added Im tired
    [VCU_tester.kicad_pcb, VCU_tester.sch]
2020-02-17 added comments
    [VCU_tester.kicad_pcb]
2020-02-17 same70-xpld footprint
    [SAME70-XPLD.kicad_pcb]
2020-02-17 beaglebone footprints
2020-02-17 de9 footprint
2020-02-17 placed vcu and beaglebone
    [VCU_tester.kicad_pcb, VCU_tester.sch]
2020-02-18 new, compact (and sexy) design
    [VCU_tester.kicad_pcb, VCU_tester.sch, motor_controller_uart.sch]
2020-02-18 forgot to save schematic
    [CAN_driver.sch, VCU_tester.sch, motor_controller_uart.sch]
2020-02-18 fix sch vcu connections
    [VCU_tester.sch]
2020-02-18 fix sch beaglebone connections
    [VCU_tester.sch]
2020-02-18 vcu & bb 3d models
    [VCU_tester.kicad_pcb]
2020-02-19 Lots of layout, power bus
    [VCU_tester.kicad_pcb, VCU_tester.sch]
2020-02-19 decouple caps, moved testpoint for usb access, tcan footprints
    [CAN_driver.sch, VCU_tester.kicad_pcb, VCU_tester.sch]
2020-02-19 better routing, tcan footprint, mount holes + silkscreen
    [CAN_driver.sch, VCU_tester.kicad_pcb, VCU_tester.sch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]
2020-02-20 reassigned brake, emsdc, audio vcurst, better testpoint
    [VCU_tester.kicad_pcb, VCU_tester.sch]
2020-02-21 add decouple caps, add gpios
    [VCU_tester.kicad_pcb, VCU_tester.sch]
2020-02-21 silkscreen, WE NEED TO CHECK CAN DB9
    [VCU_tester.kicad_pcb, VCU_tester.sch]
2020-02-21 rs232/can fix
    [CAN_driver.sch, VCU_tester.kicad_pcb, motor_controller_uart.sch]
2020-02-21 rs232 fix
    [VCU_tester.kicad_pcb, motor_controller_uart.sch]
2020-02-21 remove comments
    [VCU_tester.sch]
2020-02-21 remove more comments
    [VCU_tester.sch]
2020-02-21 silkscreen fix
    [VCU_tester.kicad_pcb]
2020-02-21 silkscreen fix2, ready to send off?
    [VCU_tester.kicad_pcb]
2020-02-21 gerbers and pdfs
    [CAN_driver.sch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]
2020-02-21 CAN pin fix, need to ground pour and done
    [CAN_driver.sch, VCU_tester.kicad_pcb]
2020-02-21 ground plane, checked, ready to go?
    [VCU_tester-B_Cu.gbr, VCU_tester-B_Mask.gbr, VCU_tester-B_SilkS.gbr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]
2020-02-22 silkscreen + neater copper fills, ready to go?
    [VCU_tester-B_Cu.gbr, VCU_tester-B_Mask.gbr, VCU_tester-B_SilkS.gbr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]
2020-02-22 clean fab notes
    [VCU_tester.kicad_pcb]
2020-02-22 add board image
2020-02-22 tidy up
    [CAN_driver.sch, SAME70-XPLD.kicad_pcb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]
